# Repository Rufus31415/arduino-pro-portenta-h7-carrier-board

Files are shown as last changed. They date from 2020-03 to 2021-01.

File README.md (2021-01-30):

More info here : https://rufus31415.github.io/arduino-portenta-h7-carrier-board.html

# About Arduino PRO Portenta H7 Carrier Board 😀
This project is an Open Source hardware board with spring terminal blocks that exposes all pins of the Arduino Pro board, for development purposes.

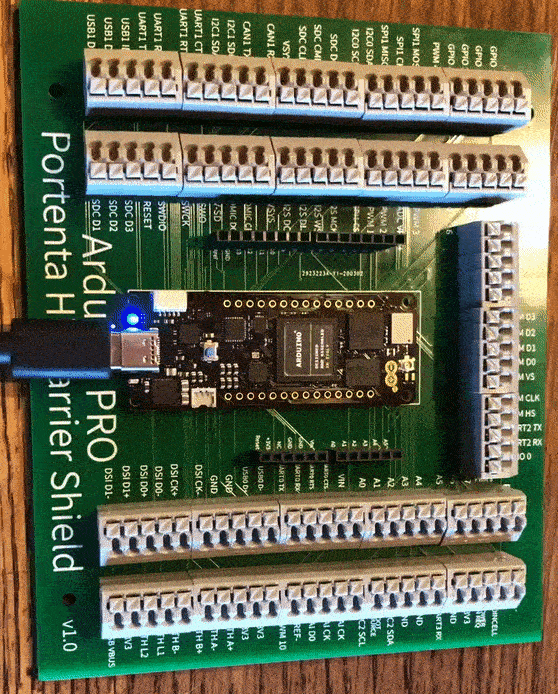
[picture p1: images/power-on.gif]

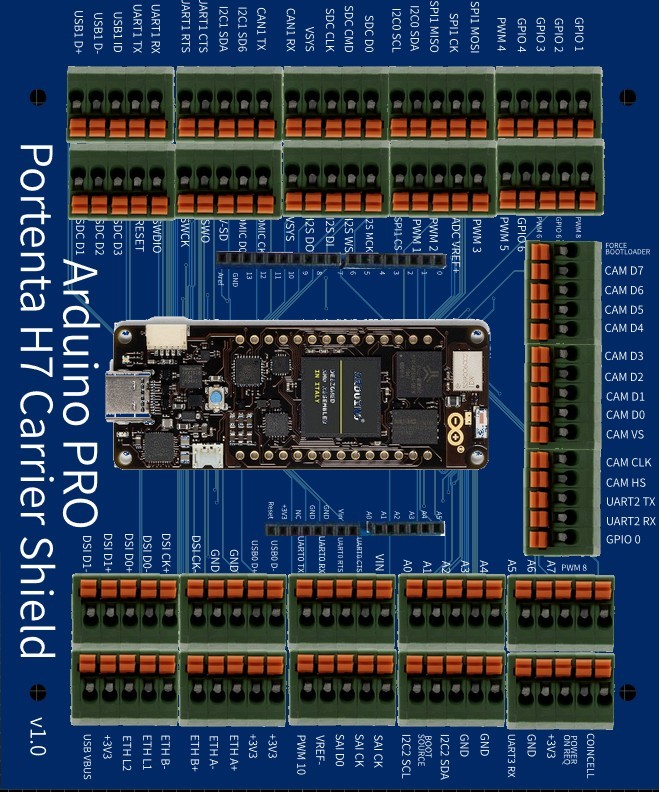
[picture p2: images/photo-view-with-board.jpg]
Arduino PRO Portenta H7 Carrier Board

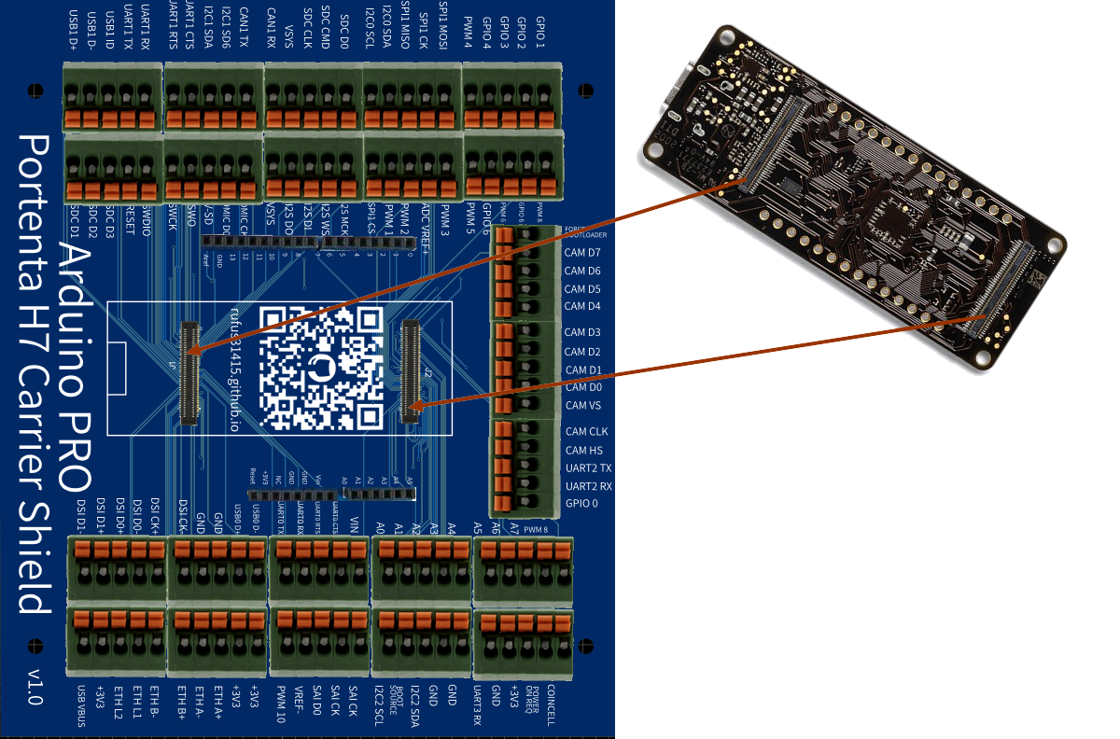
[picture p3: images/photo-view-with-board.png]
Arduino PRO Portenta H7 Carrier Board


# Order
I regularly make several of these boards, if you are curious, let me know (rufus31415@gmail.com). I only make them if enough people are interested.

It is approximately : shipping + 50€ / piece.

# Arduino Uno shield compatible 👍

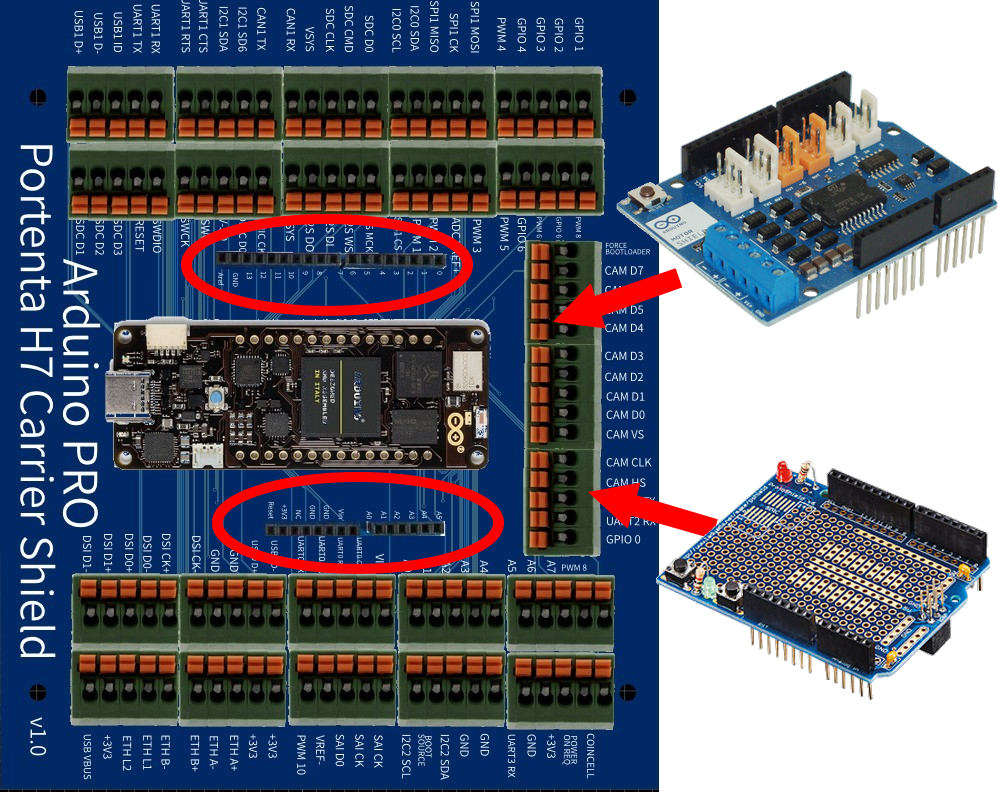
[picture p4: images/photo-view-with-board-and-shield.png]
Arduino PRO Portenta H7 Carrier Board


# Download schematics and PCB 🤓
- [Altium](https://raw.githubusercontent.com/Rufus31415/arduino-pro-portenta-h7-carrier-board/master/Altium)
- [Sources EasyEAD](https://raw.githubusercontent.com/Rufus31415/arduino-pro-portenta-h7-carrier-board/master/EasyEAD)
- Online EasyEDA : [https://easyeda.com/Rufus31415/sheetshield](https://easyeda.com/Rufus31415/sheetshield)

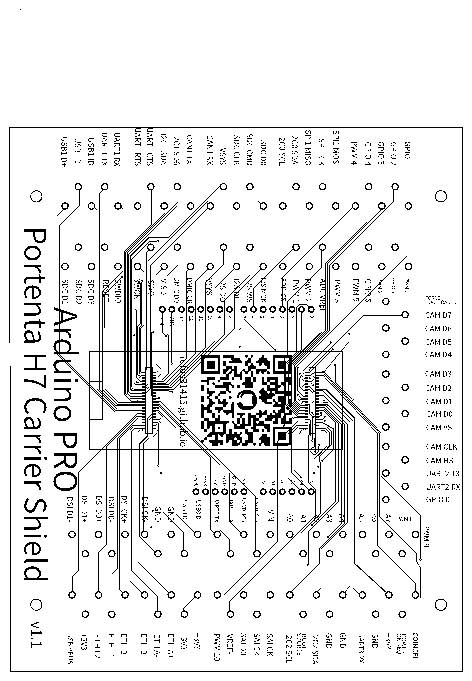
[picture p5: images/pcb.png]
Arduino PRO Portenta H7 Carrier Board PCB

Arduino PRO Portenta H7 Carrier Board Schematics

# Components 😺
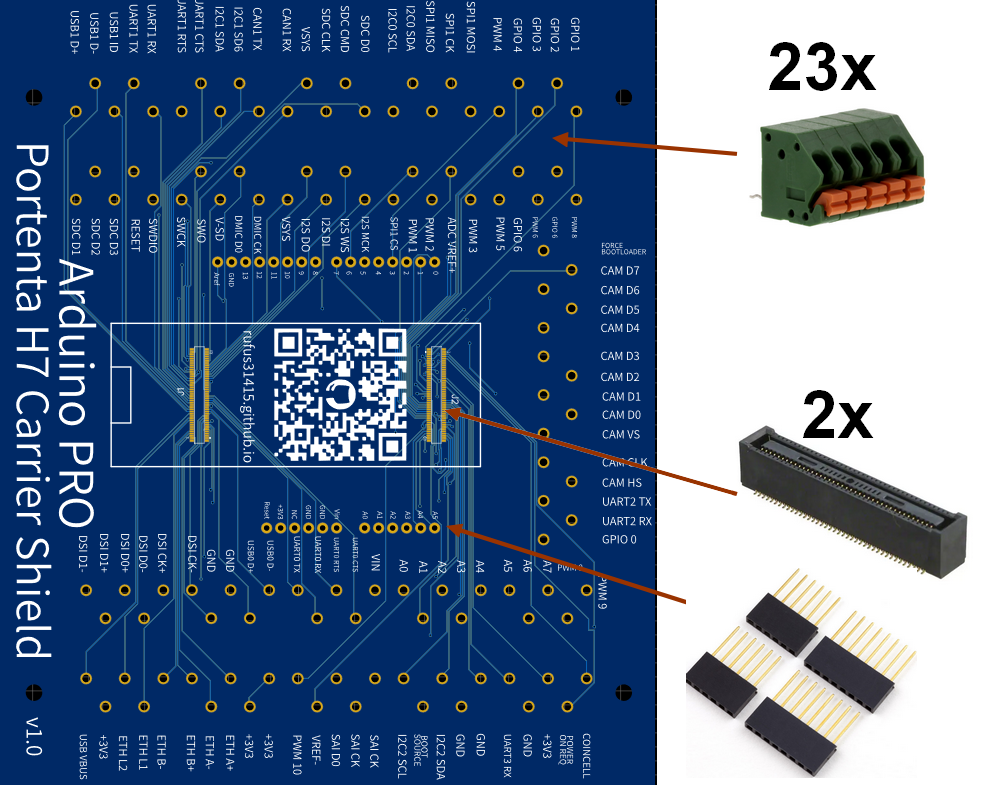
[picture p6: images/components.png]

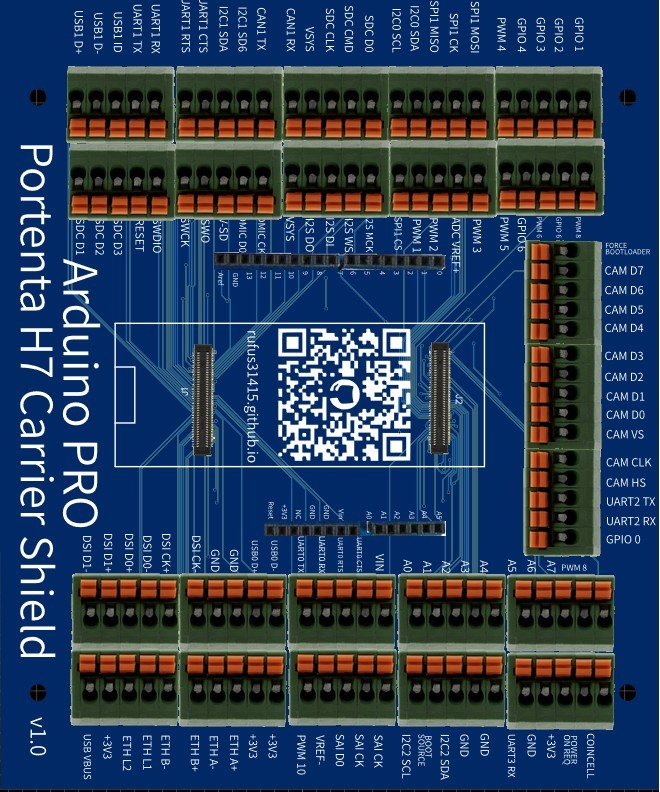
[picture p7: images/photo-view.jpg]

## Bill of material
Made in Europe :
- PCB design : PCBWay, PCB Pool (80€ for 10 pieces)
- 23 x Terminal blocks : TE Connectivity 1-2834011-3 (10€)
- 4 x Female headers : ~2€
- 2 x High density connectors : Hirose DF40C-80DS-0.4V(51) (3.5€)

TOTAL for 1 board : 25€

Made in China :
- PCB design : JLPCB (~$15 for 10 pieces + $10 shipping)
- 23 x Terminal blocks : LCSC	Ningbo Kangnex Elec WJ250B-3.5-5P ($3)
- 4 x Female headers : LCSC ($0.1)
- 2 x High density connectors (no equivalent found in China) : Hirose DF40C-80DS-0.4V(51) (3.5€)

TOTAL for 1 board : ~$8

# Watch the [tutorial on Youtube](https://www.youtube.com/watch?v=Un0XpUKotuo)

Here is a short video detailing the steps to make this card yourself.

(https://www.youtube.com/watch?v=Un0XpUKotuo)

# About Arduino PRO 🌈
Arduino PRO ([https://store.arduino.cc/portenta-h7](https://store.arduino.cc/portenta-h7)) is a new Arduino MKR board with dual core processor, USB-C, Display port, Ethernet, Wifi, Bluetooth, ... It can run Arduino Sketches, Javascript, Python or TensorFlow models.
It has two 80 pins connectors. All pins are available on this carrier board.

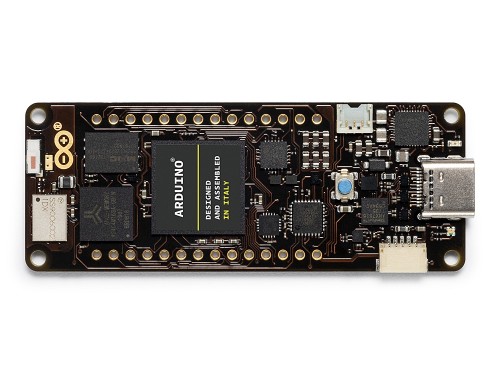
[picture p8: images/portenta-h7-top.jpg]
Arduino PRO Portenta H7 Top

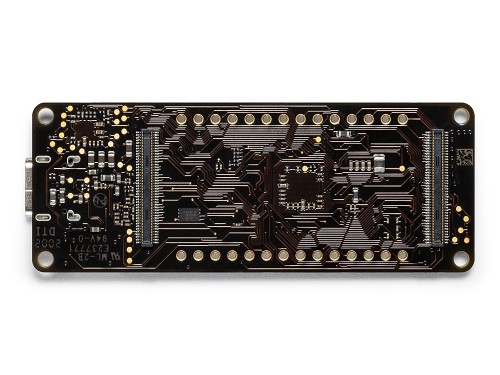
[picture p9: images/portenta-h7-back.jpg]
Arduino PRO Portenta H7 Back


# Modifications
- v1.1 :
  - Move hight density connector J1 from X=-20mm to X=-20.2mm
  - Delete the 4 external pins for hight density connector
  - Enlarge the footprint of high-density connectors (pin width from 25.98mil to 30.98mil)
  - Enlarge to 0.28mm track width for GND, 3.3V, VSYS
  - Link pin GND 54 of J1 to Shield header GND

# License: MIT 😘

© [Rufus31415](https://rufus31415.github.io)

See the [license file](https://github.com/Rufus31415/arduino-pro-portenta-h7-carrier-board/blob/master/LICENSE) for details.

<details>
<summary></summary>

</details>

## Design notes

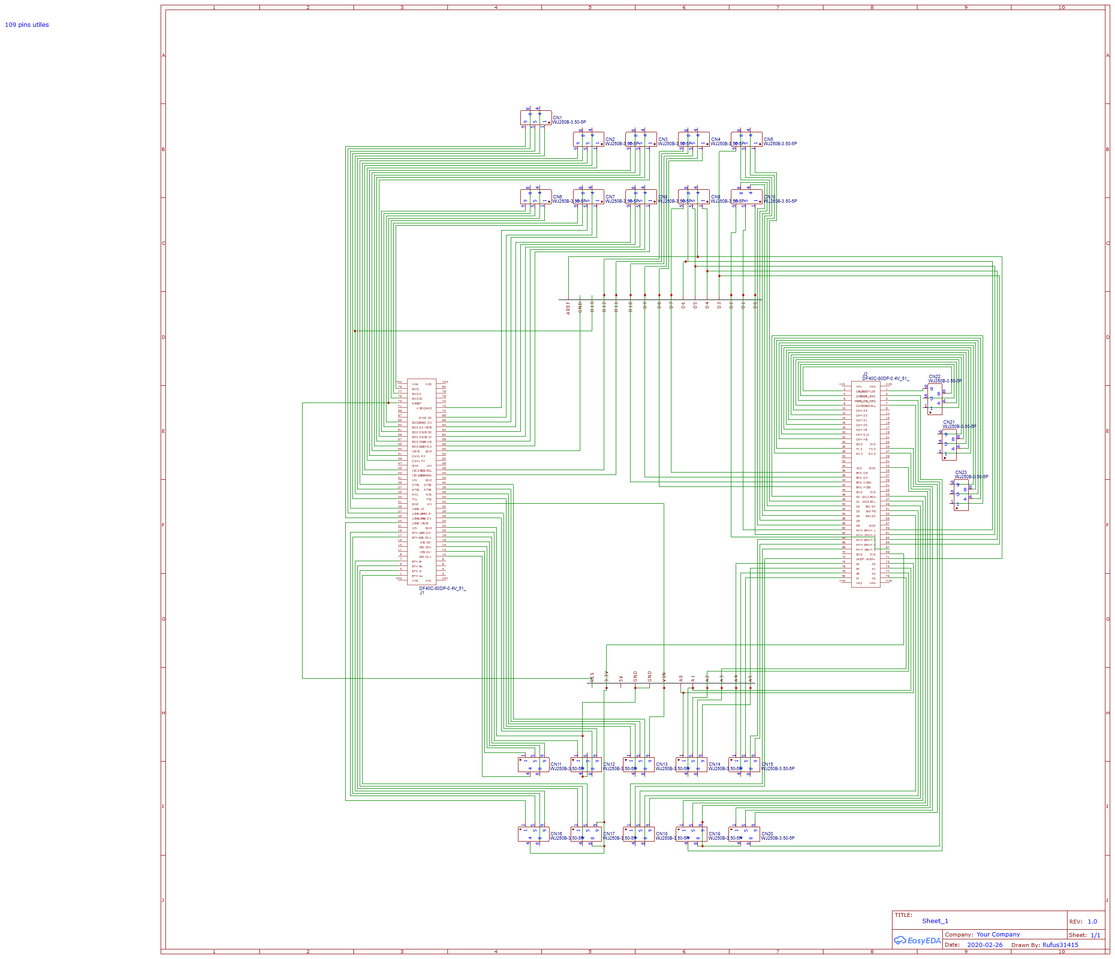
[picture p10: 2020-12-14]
images/schematics.png

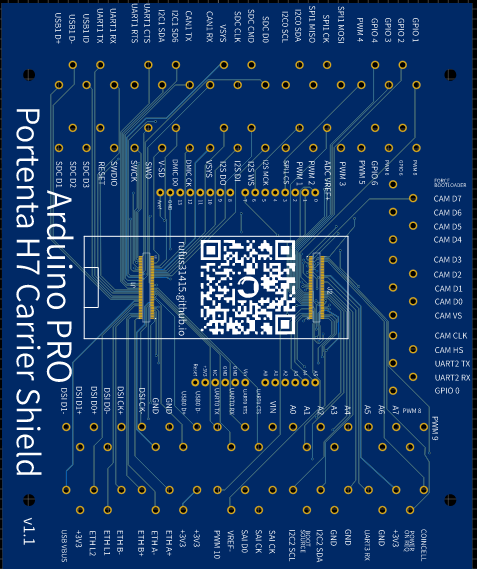
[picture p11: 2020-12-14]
images/photo-view.png

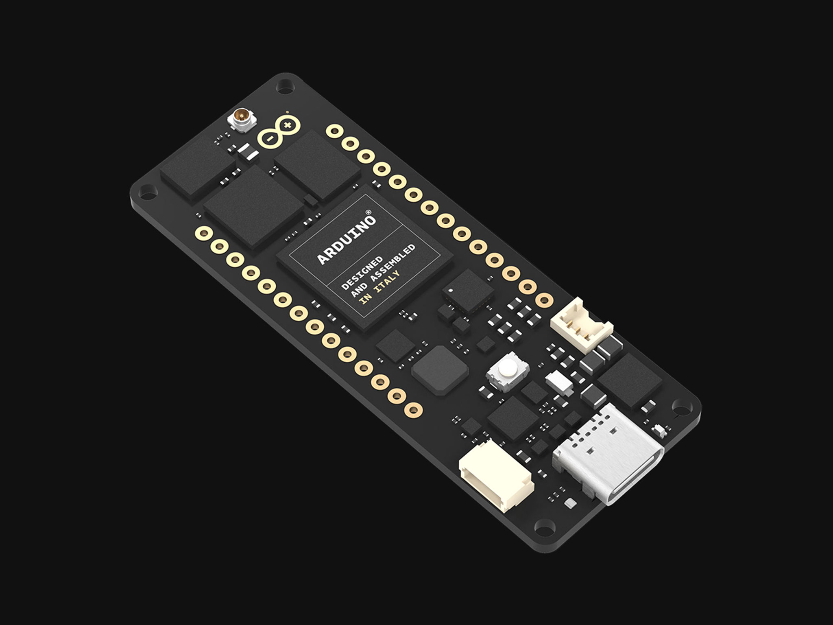
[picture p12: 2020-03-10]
images/portenta-h7.jpg

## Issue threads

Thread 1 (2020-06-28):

Add USB and Ethernet connectors

Rufus31415, 2020-06-28:
Study the replacement of some terminal block by an Ethernet and USB connector.

pnndra, 2020-06-29:
would suggest to add also SD card

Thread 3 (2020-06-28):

Wiring multiple power pins

Rufus31415, 2020-06-28:
Only one 3.3v, GND, ... are connected. Power tracks are too thin.

pnndra, 2020-06-29:
please note that each DF40 pin can sustain at most 300 mA. the board can provide up to 1A to external loads on 3.3V so it's highly recommended to have all the pins routed

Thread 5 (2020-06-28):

Correct routing of differential pairs

Rufus31415, 2020-06-28:
Some signals need to be routed with special rules, such as CAN, USB, and Ethernet.

Rufus31415, 2020-06-28:
Taking impedance into account

pnndra, 2020-06-29:
i would just suggest to avoid routing differential signals like USB, mipi, ethernet etc to the plug in connectors as it would never be possible to keep impedance matching. this has already been captured in #1

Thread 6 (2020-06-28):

High-density connector footprint is too narrow

Rufus31415, 2020-06-28:
Very difficult to solder by hand and to check the alignment because the pads are hidden by the component.

Closed 2020-12-14.

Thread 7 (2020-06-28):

Have a tool to ensure the distance between the two connectors

Rufus31415, 2020-06-28:
The gap between the 2 connectors is very important and should be constrained

pnndra, 2020-06-29:
we can provide you with an altium project template with preplaced connectors

swittman, 2020-08-12:
@pnndra I'm also interested in this, but rather for CircuitMaker. In the short term, can you verify what the spacing between the two connectors should be? Is there any plan to provide pre-composed footprints/CAD though a library like Octopart?

Closed 2020-12-14.

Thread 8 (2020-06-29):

Unconnected header pins

Rufus31415, 2020-06-29:
One GND and one 3.3v is not connected on headers for arduino shield

Rufus31415, 2020-12-14:
GND pin has been connected in v1.1

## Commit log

2020-03-10 add schematics and images
2020-03-10 move images add Altium and EasyEDA files
    [pcb.pcbdoc, schematics.schdoc]
2020-12-14 #2 Remove right angle in route #6 Enlarge connector footprints #7 change distance between connectors and build a special tool for soldering
    [pcb.pcbdoc, schematics.schdoc]
